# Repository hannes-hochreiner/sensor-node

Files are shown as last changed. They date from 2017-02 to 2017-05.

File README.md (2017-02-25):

# Sensor Node
A simple wireless sensor node.

## Requirements
  * measurements of temperature and humidity
  * wireless operation
  * cost of parts for one node <= 30 EUR
  * one measurement per minute, if a change larger than 10 % is observed; otherwise, one measurement every 10 minutes

  * MCU architecture needs to be ARM Cortex M0 (because I was interested in the platform as a replacement for AVR MCUs)
  * no leadless parts (because I was not equiped to solder them)

## Outline
The plan was to just quickly throw together a sensor, an MCU, a wireless module and a battery.

### MCU selection
I choose to go with the EFM32ZG222F32, because it was fairly cheap, low power and seemed to have good documentation.
As a bonus it has AES encryption functions, which makes the radio selection easier.
I also checked out Silicon Labs IDE and quite liked it.

Other candidates where the LPC81/2 (higher power and no AES) and the STM32F03 (no AES).

### Sensor selection
Adafruit Si7021 breakout board.
Seems to be a good sensor, which I could get my hands on for a reasonable price.
My preference would have been to use the sensor without the breakout board, but since it came in a leadless package I needed the breakout board.

### Wireless chip selection
The Si4012, because it is cheap and has very good documentation.

## Details

### Power and decoupling for the EFM32ZG
I found the recommended power and decoupling setup in Silicon Labs' "AN0002 Hardware Design Considerations".
The summary is, VSS go directly to ground, VDD_DREG gets 0.1 µF and 10 µF, DECOUPLE gets 1 µF, IOVDD get 0.1 µF each and one 10 µF, and AVDD get 10 nF each and one 10 µF.

### Power and decoupling for the Si4012
I followed the recommendation of the datasheet.
VDD got 1µF and the power supply for TXM and TXP got an LC filter with 220 nH and 0.5 pF resulting in a band pass of about 480 MHz.

### Power and decoupling for the Si7021
Ground was connected to a GPIO to be able to disable the module when it is not in use.
Decoupling has to be checked.

### External oscillators
I figured that I did not need any external oscillators since the communication on the board worked over I2C (which has a clock signal) and the radio claimed to have an internal oscillator that was precise enough.

### I2C
The three major things to consider with I2C seemed to me to be the addresses that are used, the speed the modules can handle and the pull-ups that are required.

Addresses and speeds are fairly easy to obtain.
A quick look into the datasheets told me the following:

  * Si7021: address: 0b1000000x; speeds: max 400 kHz; does clock strechting over 100 kHz.
  * Si4012: address: 0b1110000x (configurable); speeds: 100 kbps and 400 kbps.

When it comes to the pull-ups, it gets a little bit trickier.
However, I found a lot of documentation on the net explaining how to calculate the suitable intervals.
I used the Texas Instruments Application Report SLVA689 from February 2015.

I started out by calculating the maximum value, which depends essentially on the bus capacitance and the speed.
The bus capacitance is the capacitance of the pins plus that of the trace.
One problem I had was that I was not able to find any values for the capacitance the pins of my chosen chips added to the bus in the datasheets.
After investigating the topic for a while, I concluded that 10 pF should be a fairly conservative assumption.

To calculate the trace capacitance, I used the online calculator of the [Missouri University of Science and Technology](http://emclab.mst.edu/pcbtlc2/microstrip/).
The required parameters I obtained from OSHPark ([2 Layer Prototype](http://docs.oshpark.com/services/two-layer/), [2 Layer 2oz 0.8mm](http://docs.oshpark.com/services/two-layer-hhdc/)).
I assumed a trace width of 10 mils.

  * <0.5 pF / cm for the 2 layer prototype service
  * <0.6 pF / cm for the 2 layer 2 oz 0.8mm service

Given that there were three ICs on the bus and that the trace length would be smaller 3 cm, I estimated that the bus capacitance should be smaller 35 pF.
From that, I calculated the maximum resistance for the pull-ups at different speeds.

  * 33 kOhm for 100 kHz
  * 10 kOhm for 400 kHz

I tried calculating the minimum values for the pull-up resistors for all ICs.
However, only the datasheet of the Si7021 provided the required values.
The minimum resistance for the Si7021 was 1.1 kOhm.
I took this value as a representative value of all involved ICs.

In the end, I decided to go with 400 kHz transmission speed using 10 kOhm pull-ups.
One thing to note is that the Si4012 had a 50 kOhm integrated pull-up.
Hence the 10 kOhm would effectively only be about 8.5 kOhm.
I figured that this should give me an additional margin, but it was also something I had to consider at the time of calculating the battery life.

### Antenna
I chose to go with a loop antenna, because I have had problems with dipole antennas in the past.
Often the dipole antennas worked fine on the breadboard, but in the finished product the performed considerable worse.
Since I don't have the equipment to do an in-depth analysis, I left with (more or less educated) guesses.
I attributed the drop in antenna performance to the fact that the breadboard was acting as a ground plane.
In the finished sensor, there was no comparable ground plane and therefore the performance was worse.
As I was trying to get the sensors as compact as possible and I did not want to go higher frequencies, I thought that loop antennas were my best shot.
They are relatively small, don't need a ground plane and can be printed on the PCB.

To tune the antenna size, I wrote a small program.
I based my calculations of the loop inductance on a NIST paper ([E.B. Rosa "The self and mutual inductances of linear conductors," Bulletin of the Bureau of Standards, vol. 4, no. 2, p. 301](http://nvlpubs.nist.gov/nistpubs/bulletin/04/nbsbulletinv4n2p301_A2b.pdf)).
This paper gave a closed form equation for the conductance of a rectangular loop, while in the application notes I could only find conversions to equivalent circular structures.
The results were within 5 % of the approximations found in the application notes.

I calculated the size of the feed loop based on two different application notes.
[Microchip AN831](http://ww1.microchip.com/downloads/en/AppNotes/00831b.pdf) seemed to use a simpler approach basically neglecting the effect of the PCB.
[Silicon Labs AN639](http://www.silabs.com/Support%20Documents/TechnicalDocs/AN639.pdf) took the effect of the PCB into account, but used empirical factors to do so.
Although I thought it would be good to take the effect of the PCB into account, I wasn't quite sure the assumptions for the empirical factors help for my design.

With both approximations, I obtained about -8 dB for the estimated gain.
The length of the feed loop came out quite differently (10.5 mm to 16.1 mm).
In the end I decided to go with 14 mm, because I figured that it would be easier to compensate for a slightly to large loop than for a slightly to small loop.

### SWD
I added a 10 pin Cortex Debug connector based on the [ARM recommendation](http://infocenter.arm.com/help/topic/com.arm.doc.faqs/attached/13634/cortex_debug_connectors.pdf).

### BOM

A detailed bill of materials can be found on a [sub-page](bom.md).

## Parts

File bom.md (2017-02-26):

# BOM

amount|description|manufacturer|supplier|price per unit / EUR
------|-----------|------------|--------|--------------------
1|[EFM32ZG222F32 QFP48 microcontroller](https://hbe-shop.de/Art-2503912-SILICON-LABS-EFM32ZG222F32-QFP48T-MCU-32BIT-CORTEX-M0-24MHZ-TQFP-48)|Silicon Labs|hbe|2.24
1|[PCB 30mm x 54mm 2oz](http://docs.oshpark.com/services/two-layer-hhdc/)|OSH Park|oshpark|4
1|box|local|local|3.5
1|[CR2032 battery holder](https://www.voelkner.de/products/8982/Knopfzellen-Batteriehalter-Hu2032-Lf.html)|renata|voelkner|0.59
1|[battery CR2032](https://www.voelkner.de/products/770689/HyCell-Knopfzelle-CR-2032-Lithium-CR-2032-200-mAh-3-V-2-St..html)|various|voelkner|0.45
2|[resistor 10kOhm](https://hbe-shop.de/Art-2447553-MULTICOMP-MCWR08X1002FTL-DICKSCHICHTWIDERSTAND-10K-1-0125W-0805)|Multicomp|hbe|0.01
1|[Si4012 rf transmitter](https://hbe-shop.de/Art-2414359-SILICON-LABS-SI4012-C1001GT-RF-TRANSMITTER-27-960MHZ-MSOP-10)|Silicon Labs|hbe|1.15
1|[inductor 220nH](https://hbe-shop.de/Art-2470315-MURATA-LQW2BASR22J00L-INDUKTIVITAET-220NH-04A-5-820MHZ)|Murata|hbe|0.22
1|[capacitor 0.5pF](https://hbe-shop.de/Art-1759178-MULTICOMP-MC0805N0R5C500CT-KONDENSATOR-MLCC-C0G-NP0-05PF-50V-0805)|Multicomp|hbe|0.04
2|[capacitor 1pF](https://hbe-shop.de/Art-7568398-AVX-08052U1R0BAT2A-HF-KONDENSATOR-C0G-NP0-1PF-200V-0805)|AVX|hbe|0.7
2|[capacitor 1µF](https://hbe-shop.de/Art-1759422-MULTICOMP-MC0805F105Z160CT-KONDENSATOR-MLCC-Y5V-1UF-16V-0805)|Multicomp|hbe|0.04
4|[capacitor 0.1µF](https://hbe-shop.de/Art-1759167-MULTICOMP-MC0805F104Z250CT-KONDENSATOR-MLCC-Y5V-100NF-0805)|Multicomp|hbe|0.02
4|[capacitor 10µF](https://hbe-shop.de/Art-2320852-MULTICOMP-MC0805X106K6R3CT-KONDENSATOR-MLCC-X5R-10UF-63V-0805)|Multicomp|hbe|0.08
2|[capacitor 10nF](https://hbe-shop.de/Art-1759246-MULTICOMP-MC0805B103K500CT-KONDENSATOR-MLCC-X7R-10NF-50V-0805)|Multicomp|hbe|0.02
1|[Si7021 humidity sensor breakout board](http://www.exp-tech.de/adafruit-si7021-temperature-humidity-sensor-breakout-board)|Adafruit|exp-tech|7.5
1|[header 1x5 straight](https://www.voelkner.de/products/130623/Praezisions-Stiftleiste-1x20-Verg-Rm-2-5.html)|BKLElectronic|voelkner|0.37
1|[socket 0.25 x 1x20 straight](https://www.voelkner.de/products/882107/Connfly-Buchsenleiste-Praezision-Anzahl-Reihen-1-Polzahl-je-Reihe-20-93040C2-1-St..html)|Connfly|voelkner|0.13
1|[Cortex Debug shrouded header](https://www.voelkner.de/products/877289/W-P-Products-Stiftleiste-Rastermass-1.27-mm-Polzahl-Gesamt-10-1-St..html)|W+P|voelkner|0.61
|**total**|||**22.74**

## Cost for 3 sensors
supplier|price of goods|shipping|total
--------|--------------|--------|-----
HBE|21.37|8.45|29.82
OSH Park|12|0|12
local shop|10.5|0|10.5
Voelkner|7.4|4.95|12.35
EXP-TECH|22.5|3.5|26
**total**|||90.67

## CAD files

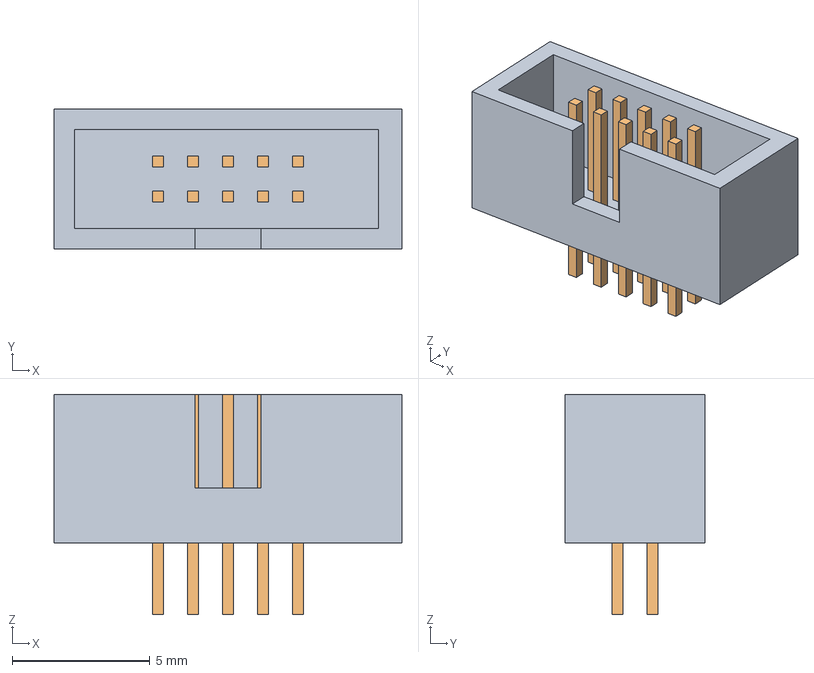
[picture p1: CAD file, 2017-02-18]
freecad/shroudedHeader.fcstd
12.7 x 5.10 x 8.00 mm
shroud
pins

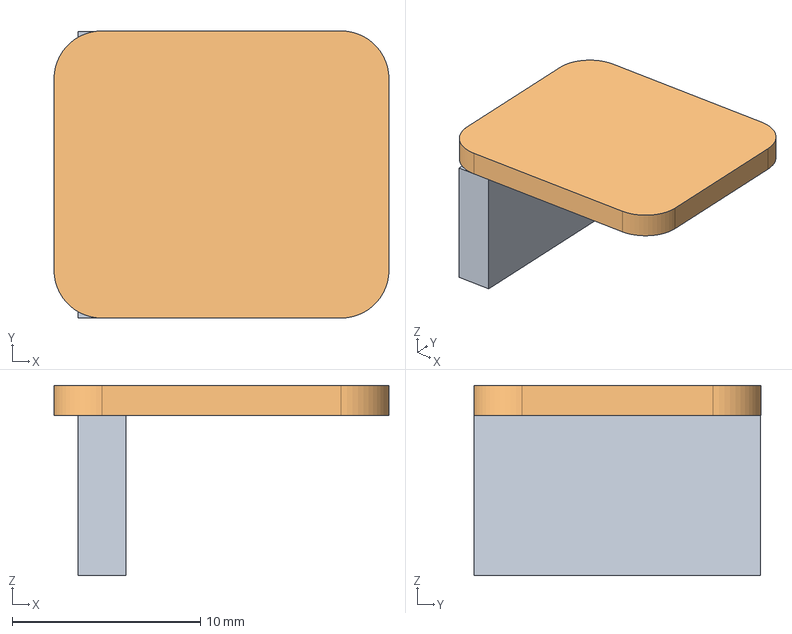
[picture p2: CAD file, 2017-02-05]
freecad/si7021_breakout.fcstd
17.8 x 15.2 x 10.1 mm
female header

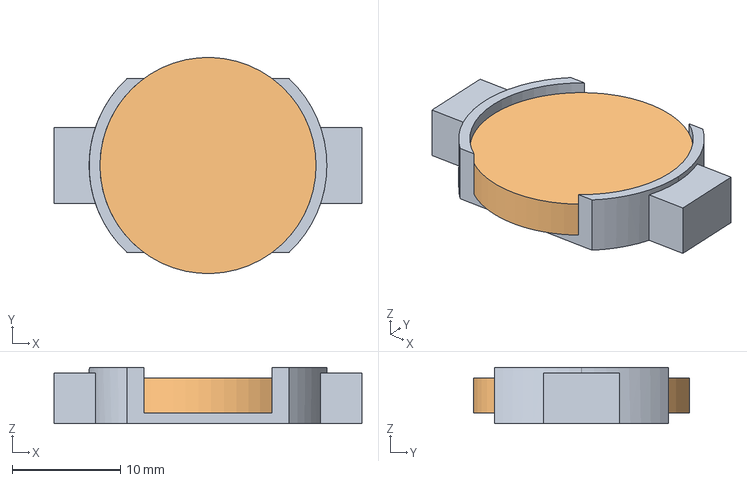
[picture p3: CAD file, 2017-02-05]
freecad/batteryHolder.fcstd
28.5 x 20.0 x 5.20 mm
battery holder
battery

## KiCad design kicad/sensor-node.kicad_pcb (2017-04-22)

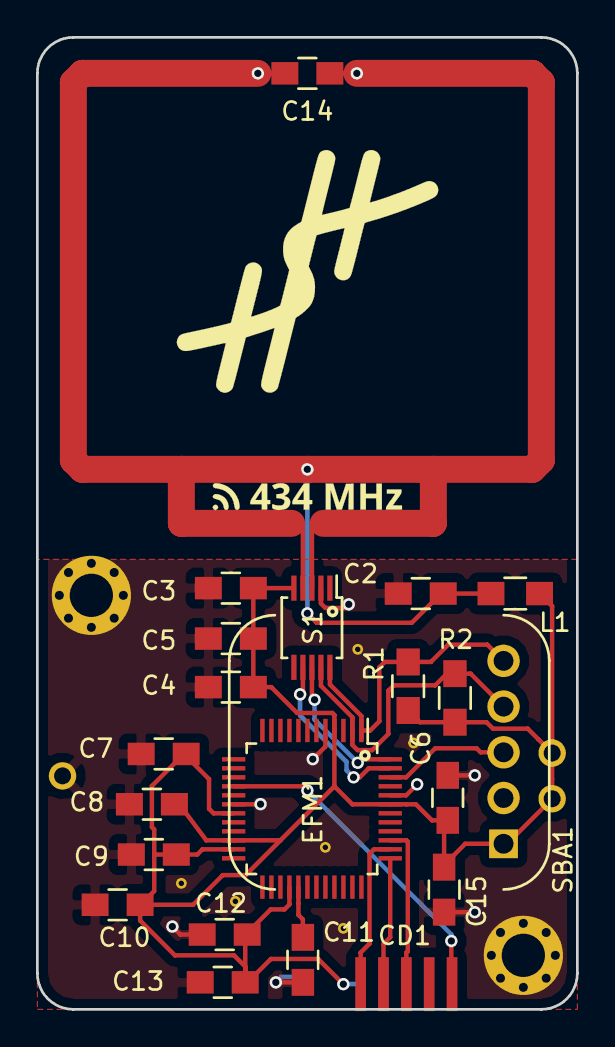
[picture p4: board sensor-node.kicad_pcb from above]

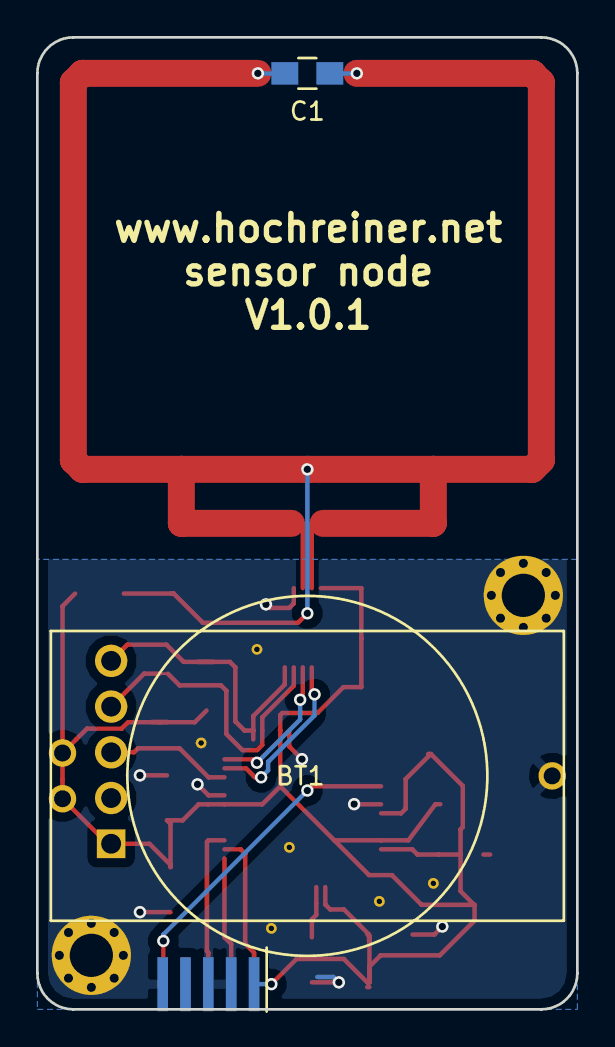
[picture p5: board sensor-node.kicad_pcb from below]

Board: 2 copper layers, 30.0 x 54.0 mm, 23 parts (2 on the bottom side), 13 nets.

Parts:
BT1: CR2032Holder; HU2032-LF
C1, C14: 1pF; C_0805_HandSoldering
C2: 0.5pF; C_0805_HandSoldering
C3, C11: 1µF; C_0805_HandSoldering
C4, C6, C8, C12: 0.1µF; C_0805_HandSoldering
C5, C10, C13, C15: 10µF; C_0805_HandSoldering
C7, C9: 10nF; C_0805_HandSoldering
CD1: CortexDebug; CORTEX-DEBUG-EDGE
EFM1: EFM32ZG222; TQFP-48_7x7mm_Pitch0.5mm
L1: 220nH; R_0805_HandSoldering
R1, R2: 10k; R_0805_HandSoldering
S1: Si4012; MSOP-10_3x3mm_Pitch0.5mm
SBA1: Si7021-BA; Si7021BA

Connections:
+3V3: BT1.1, C3.1, C4.1, C5.1, C6.2, C7.1, C8.1, C9.1, C10.1, C12.1, C13.1, C15.2, CD1.1, EFM1.4, EFM1.19, EFM1.22, EFM1.23, EFM1.28, EFM1.43, L1.1, R1.2, R2.2, S1.5, SBA1.1
/RAD_ENABLE: EFM1.48, S1.8
/RAD_INT: EFM1.47, S1.7
/SCL: EFM1.2, R2.1, S1.9, SBA1.4
/SDA: EFM1.1, R1.1, S1.10, SBA1.5
/SWCLK: CD1.4, EFM1.37
/SWDIO: CD1.2, EFM1.38
/SWO: CD1.6, EFM1.39
/~RESET: CD1.10, EFM1.16
/~SEN_ENABLE: EFM1.46, SBA1.3
GND: BT1.2, C2.2, C3.2, C4.2, C5.2, C6.1, C7.2, C8.2, C9.2, C10.2, C11.1, C12.2, C13.2, C15.1, CD1.3, CD1.5, CD1.9, EFM1.5, EFM1.18, EFM1.44, S1.2
unnamed: C1.1, C1.2, C2.1, C14.1, C14.2, L1.2, S1.3, S1.4
unnamed: C11.2, EFM1.29

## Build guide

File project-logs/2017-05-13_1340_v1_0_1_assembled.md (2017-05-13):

# Version 1.0.1 assembled

Today, I mostly assembled one of the version 1.0.1 boards.
For the time being, I left out the sensor socket and the battery.
The sensor I already tested and I can't attach the battery holder as long as sensor socket is not attached.

The electrical and first MCU communication tests looked ok.
Next up are the radio chip tests.
Followed, of course, by the actual radio transmission test.

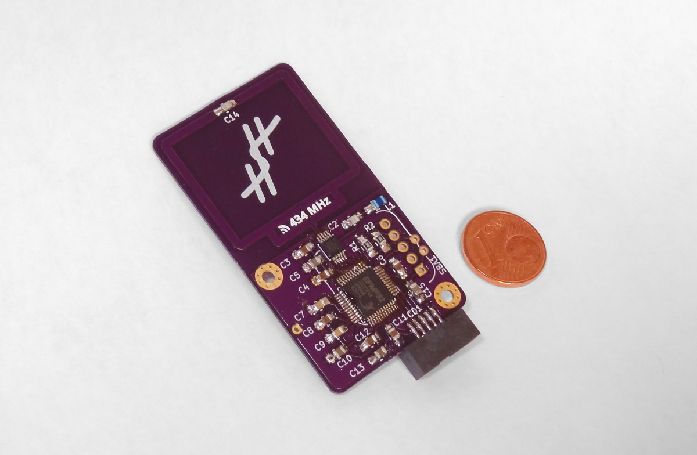
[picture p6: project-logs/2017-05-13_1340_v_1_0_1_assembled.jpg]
pcb version 1.0.1 assembled


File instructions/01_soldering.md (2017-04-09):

# Soldering
The order for soldering the components that worked best for me so far was:

  * MCU
  * capacitors
  * radio IC
  * rest

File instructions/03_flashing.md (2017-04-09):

# Flashing the MCU
I decided to use the Adafruit FT232H breakout board in combination with OpenOCD for flashing the MCU.

## Installing OpenOCD
Since I was using Fedora at the time, installing OpenOCD was as easy as typing:

```
sudo dnf install -y openocd
```

## FT232H module configuration
I started out using the "resistor hack" (interface/ftdi/swd-resistor-hack.cfg) configuration.
It worked ok, but had the drawback that it needed additional parts.

There is an ["official" configuration](http://openocd.zylin.com/#/c/2274) being worked on.
Hence, I am hopeful that the support for the FT232H module will get better soon.
For the time being, I pieced together a configuration with what I found around the web.
It is mainly based on [adafruit-ft232h-swd.cfg](http://openocd.zylin.com/#/c/4075/1/tcl/interface/ftdi/adafruit-ft232h-swd.cfg) by Roger Lendenmann.

## Connecting the adapter
The adapter connection is described in [adafruit-ft232h-swd.cfg](http://openocd.zylin.com/#/c/4075/1/tcl/interface/ftdi/adafruit-ft232h-swd.cfg).

## Flashing the chip
To flash the chip, I started OpenOCD in one terminal.
```
cd openocd
openocd -f sensor-node.cfg
```

Then, I opened a second terminal to connect to it via telnet.
```
$ telnet localhost 4444
Trying 127.0.0.1...
Connected to 127.0.0.1.
Escape character is '^]'.
Open On-Chip Debugger
> program ../sensor-node.hex verify reset
target halted due to debug-request, current mode: Thread
xPSR: 0x81000000 pc: 0x00000164 msp: 0x20001000
** Programming Started **
auto erase enabled
detected part: EFM32 Zero Gecko - Rev: 139
flash size = 32kbytes
flash page size = 1024bytes
wrote 3072 bytes from file ../sensor-node.hex in 0.180560s (16.615 KiB/s)
** Programming Finished **
** Verify Started **
verified 2888 bytes in 0.036852s (76.531 KiB/s)
** Verified OK **
```

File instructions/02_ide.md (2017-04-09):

# IDE
I used "Simplicity Studio" as the IDE.
To install it, I followed the instructions on the Silicon Labs website.

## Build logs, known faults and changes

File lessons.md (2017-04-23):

# Lessons learned

  * The card edge contacts for the SWD connector (0.05" pitch) work perfectly with the OSH Park 2oz boards
  * An additional pin 1 indicator is required for the MSOP10 and QFP48 footprints in KiCAD as the ones included in the default footprints are not visible on the PCBs
  * The decoupling capacitors are really important
  * It is really nice to be able to debug programs on the chip

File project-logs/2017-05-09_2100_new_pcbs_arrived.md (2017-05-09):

# New PCBs arrived!

Big shout-out and thank you to [OSH Park](https://oshpark.com/) who did everything in his power to deliver the new version of my board as fast as possible!
While I expected that the new PCBs would take 5-6 weeks to arrive, it took little more than 2 weeks.
Really exceptional service.

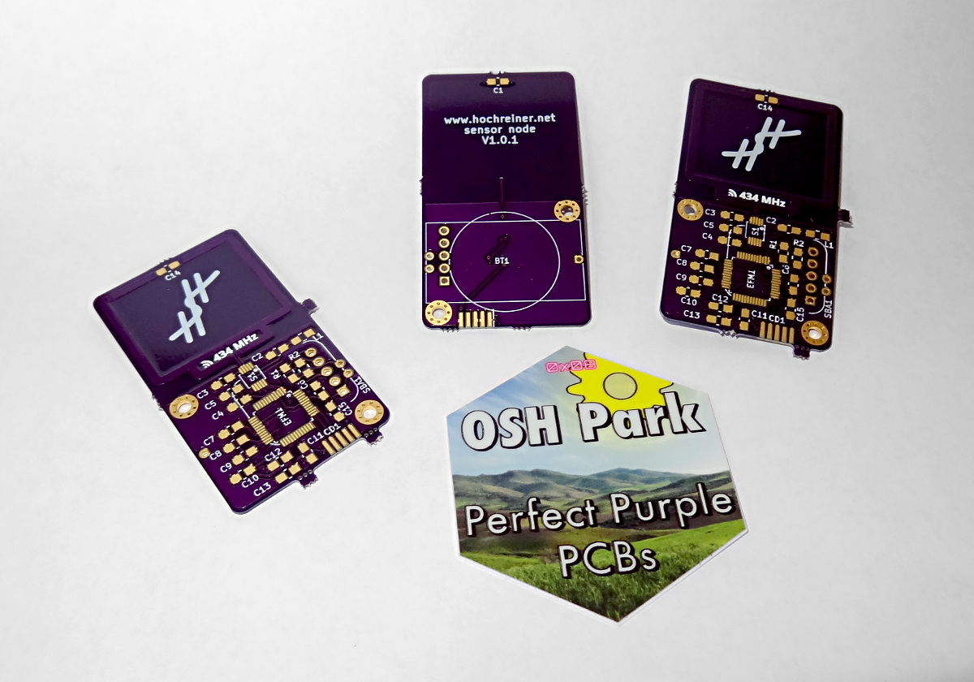
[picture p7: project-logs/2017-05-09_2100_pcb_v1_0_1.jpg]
pcb version 1.0.1 on arrival


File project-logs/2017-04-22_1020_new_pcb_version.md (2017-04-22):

# New version of the board ordered

Today, I ordered version 1.0.1 of the board from [OSH Park](https://oshpark.com/).
With this version, I fixed the pin assignment of the radio chip, added pin 1 indicators for the MCU and the radio chip, and added more ground plane copper on the top layer.
It will probably take more than a month until I get the boards delivered, but I am really looking forward to playing with them.

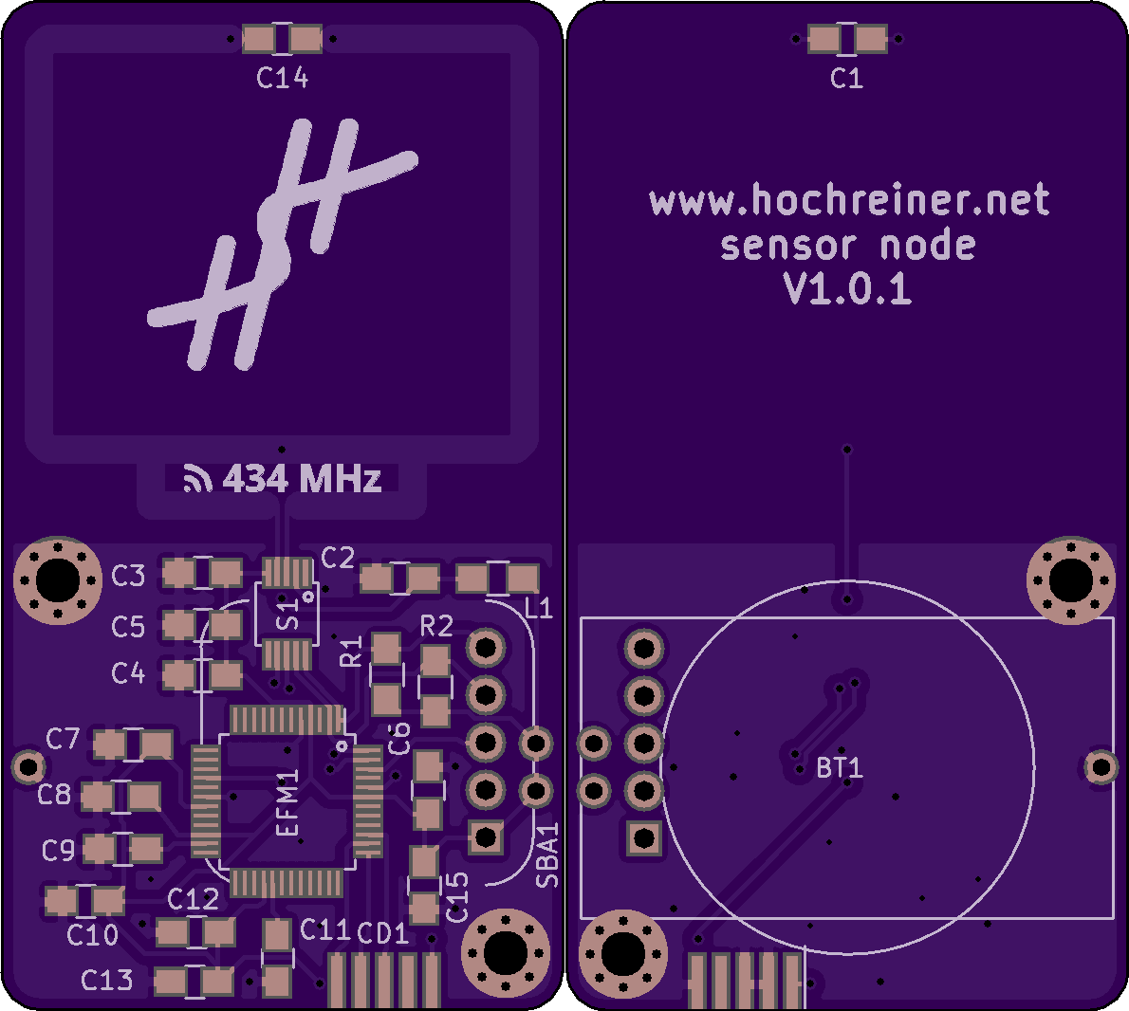
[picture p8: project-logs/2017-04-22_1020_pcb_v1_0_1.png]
pcb version 1.0.1


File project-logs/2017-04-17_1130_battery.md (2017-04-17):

# Battery operation test completed

I finally ran the last test I wanted to do with the current version of the board: the battery operation test.
Since it was unclear to me from the documentation of the sensor breakout board whether it would operate normally below 3.3 V, I gave it a try.
I powered the board from the CR2032, which my multi-meter claimed to be 3.05V, and looked at the measurement results in the debugger.
Everything, seemed to work fine.
The next step will be to order a new batch of boards with the correct pin assignment for the radio chip.
I am really looking forward to seeing the full assembly work.

Background on the breakout board power confusion:
On the [Adafruit description page](https://learn.adafruit.com/adafruit-si7021-temperature-plus-humidity-sensor) of the breakout board it claims to work from 3-5 volts input and both 3.3V and 5V logic.
However, I also had a look at the circuit diagram and the model of regulator chip ([Microchip MIC5225-3.3](http://www.microchip.com/wwwproducts/en/MIC5225)) that has been used.
This chip is rated to output 3.3V with a dropout voltage of typically about 300mV at full load.
My confusion was mainly that I thought that below about 3.3V (actually rather 3.6V) it would not work.
This did not fit with the documentation and also did not reflect what I experienced powering the breakout board from a 3.3V source.
Now that I tried with a 3V source and had another read of the data sheet, I think the more accurate interpretation is that below 3.6V the regulator chip rated for 3.3V cannot provide the 3.3V anymore.
Even so, it does not go to zero straight away.
There is actually a nice graph in the data sheet showing the output voltage remains about 0.5V below the input voltage down to about 2.3V.
Only then it drops to zero.
Since the sensor chip works down to 1.9V, everything should work out just fine down to a battery voltage of about 2.4V.

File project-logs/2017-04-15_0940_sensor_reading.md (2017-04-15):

# Reading sensor values
Reading the sensor values turned out to be pretty straight forward.
The emlib provides a nice abstraction for handling I2C communication.
Furthermore, there are a few examples that can be found around the web.
In the first iteration, I took the simplest approach by using blocking mode (clock stretching) requests.
I think that I could gain some efficiency in setting up DMA driven I2C communication, but I figured it might be better to start simple.

The actual code can be found on [GitHub](https://github.com/hannes-hochreiner/sensor-node/blob/08b46bc856f15618d4c0e9fb8b632ffcaa449f23/firmware/src/main.c).
I used GDB to load and debug the code on the MCU.
Having only worked with 8-bit AVR, I really enjoyed being able to debug the code directly on the MCU.
Although I cannot debug the code right in the IDE, it is still so much better to have GDB session with full access to memory and breakpoints than trying to debug code using printf and blinking LEDs.

For completion, here is a condensed version of the GDB session:
I started OpenOCD in one terminal:
```
$ openocd -f sensor-node.cfg
```
Then, I opened a second terminal to start GDB:
```
$ arm-none-eabi-gdb sensor-node.axf
(gdb) target remote :3333
(gdb) monitor reset halt
(gdb) load `sensor-node.axf' has changed; re-reading symbols.
Loading section .text, size 0x166c lma 0x0
Loading section .ARM.exidx, size 0x8 lma 0x166c
Loading section .data, size 0x74 lma 0x1674
Start address 0x164, load size 5864
Transfer rate: 12 KB/sec, 1954 bytes/write.
(gdb) b main.c:50
(gdb) c
Continuing.

Breakpoint 1, main () at ../src/main.c:50
50          for(volatile long i=0; i<100000; i++)
(gdb) p ret
$1 = i2cTransferDone
(gdb) p/x rx_buffer
$2 = {0x7b, 0x7e}
```
Which yielded the plausible value of about 54% relative humidity.

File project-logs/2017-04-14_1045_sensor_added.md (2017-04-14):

# Sensor added

I just added the I2C pull-ups and the sensor socket to the board.
For the time being, this is the final state of this version of the board.
There is no point in adding the radio components, as the pin assignment has to be corrected.
However, I can attach the sensor and test the communication between the sensor and the MCU now.

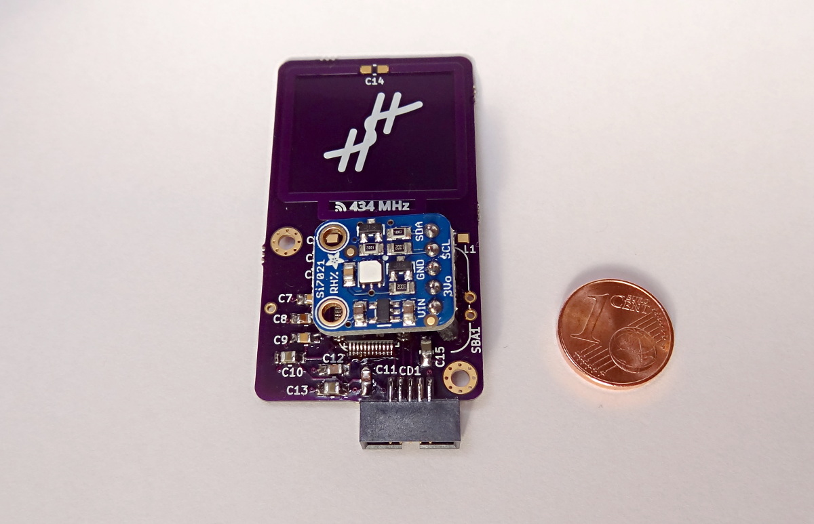
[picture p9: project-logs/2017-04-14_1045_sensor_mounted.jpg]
test board with the sensor attached


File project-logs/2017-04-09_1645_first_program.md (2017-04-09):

# First program
Today, I learned an interesting lesson: decoupling capacitors matter.

For the last few days, I had been stuck with a problem: reading from the MCU worked, but flashing a new program always failed.
I started going through all possible causes (OpenOCD configuration, physical connections, ...), but I could not find the cause of the problems.
Then I remembered reading recently that the decoupling capacitors are not only there to cope with ripples in the power supply, but also to smooth out the varying power demand of the MCU.
Therefore, I decided to add the decoupling capacitors and give the board another try:

```
> program sensor-node.hex verify
target halted due to debug-request, current mode: Thread
xPSR: 0x01000000 pc: 0x00000164 msp: 0x20001000
** Programming Started **
auto erase enabled
wrote 3072 bytes from file sensor-node.hex in 0.173291s (17.312 KiB/s)
** Programming Finished **
** Verify Started **
verified 2888 bytes in 0.036685s (76.879 KiB/s)
** Verified OK **
```

Fortunately this time everything worked without errors.

Coming from a background of working with Atmel 8-bit chips, which work quite well without decoupling, the solution to this problem was not all that obvious to me.
However, I think it was a valuable lesson in building robust designs.

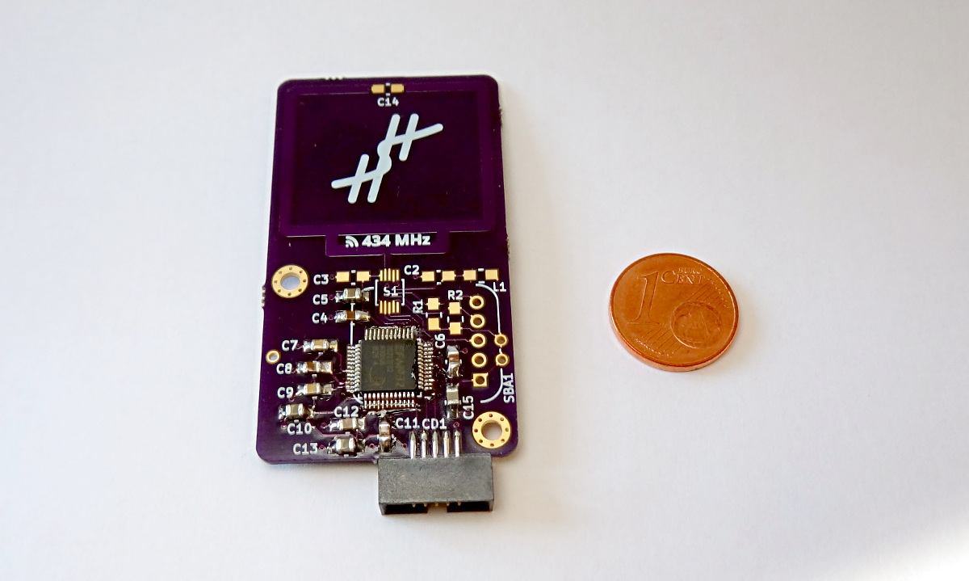
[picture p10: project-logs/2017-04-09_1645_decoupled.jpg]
sensor node board with decoupling capacitors added


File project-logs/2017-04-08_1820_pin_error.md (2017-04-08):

# Wrong pin assignment

As I was getting ready to solder the radio chip (Si4012), I realized that the pin assignment for this chip was wrong.
This is - obviously - not ideal.
While the problem is easily fixable and the financial hit of ordering new boards is bearable (< 15 EUR), the additional delay (3-5 weeks) is quite severe.
However, there are still a few things I can do with the boards as they are now:

  * check that programming the MCU works
  * check the communication with the sensor
  * check that the sensor works with the voltage the battery is able to supply

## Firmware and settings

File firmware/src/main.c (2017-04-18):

#include "em_device.h"
#include "em_chip.h"

#include "InitDevice.h"
#include "sensor.h"

int main(void)
{
  /* Chip errata */
  CHIP_Init();

  // Add some delay
  for(volatile long i=0; i<200000; i++)
    ;

  enter_DefaultMode_from_RESET();

  /* Infinite loop */
  while (1) {
    uint16_t hum, tmp;

    readSensor(&hum, &tmp);

    // Add some more delay
    for(volatile long i=0; i<100000; i++)
      ;
  }
}

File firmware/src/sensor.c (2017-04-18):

/*
 * sensor.c
 *
 *  Created on: Apr 18, 2017
 *      Author: Hannes Hochreiner <hannes@hochreiner.net>
 */

#include "sensor.h"

int readSensor(uint16_t* humidity, uint16_t* temperature) {
  I2C_Init_TypeDef i2c_init = {
    .enable = true,                              // enable I2C
    .master = true,                              // I2C master
    .refFreq = 0,                                // measure reference clock
    .freq = I2C_FREQ_FAST_MAX,                   // 400kbps fast mode
    .clhr = i2cClockHLRAsymetric,                // use 6:3 bit ratio
  };
  I2C_Init(I2C0, &i2c_init);

  uint8_t sensor_addr = 0x40;
  uint8_t comReadHumidity = 0xE5;
  uint8_t comReadTemperature = 0xE0;
  uint8_t buf[2];

  I2C_TransferReturn_TypeDef ret; // I2C state tracker

  I2C_TransferSeq_TypeDef msg = {
    .addr = (sensor_addr << 1),            // set sensor slave address
    .flags = I2C_FLAG_WRITE_READ,          // indicate basic write
    .buf[0].data = &comReadHumidity,       // point to tx_buffer
    .buf[0].len = 1,                       // specify number of bytes
    .buf[1].data = buf,
    .buf[1].len = 2
  };

  ret = I2C_TransferInit(I2C0, &msg);      // start I2C write transaction with sensor
  while(ret == i2cTransferInProgress) {    // continue until all data has been sent
    ret = I2C_Transfer(I2C0);
  }

  *humidity = buf[0] << 8 | buf[1];

  msg.buf[0].data = &comReadTemperature;

  ret = I2C_TransferInit(I2C0, &msg);      // start I2C write transaction with sensor
  while(ret == i2cTransferInProgress) {    // continue until all data has been sent
    ret = I2C_Transfer(I2C0);
  }

  *temperature = buf[0] << 8 | buf[1];

  return 0;
}

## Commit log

2017-01-10 updated the sensor selection
2017-01-12 started circuit diagram
    [sensor-node.kicad_pcb, sensor-node.sch]
2017-01-14 added basic wiring for the MCU and the radio
    [sensor-node.sch]
2017-01-14 added sensor
    [sensor-node.sch]
2017-01-14 added I2C design
2017-01-19 updated pull-up values in the diagram
    [sensor-node.sch]
2017-01-21 added debug connector
    [sensor-node.sch]
2017-01-21 fixed some minor problems
    [sensor-node.sch]
2017-01-21 added some annotation
    [sensor-node.sch]
2017-01-21 started working on an antenna design tool
2017-01-22 added capacitance calculation
2017-01-22 added the velocity factor for the calculation of the radiation resistance
2017-01-22 updated the calculation of the trace resistance
2017-01-22 switched formatting
2017-01-22 switched tests to use d3-format
2017-01-24 started board layout
    [sensor-node.kicad_pcb, sensor-node.sch]
2017-01-24 started routing
    [sensor-node.kicad_pcb]
2017-01-24 extended bom
2017-01-25 added custom footprints
    [sensor-node.kicad_pcb, sensor-node.sch]
2017-01-26 continued routing
    [sensor-node.kicad_pcb]
2017-01-28 automated bom creation and moved it to a separate page
    [sensor-node.sch]
2017-01-28 added link to bom
2017-01-28 removed led
    [sensor-node.kicad_pcb, sensor-node.sch]
2017-01-28 removed uart
2017-01-28 updated bom
2017-01-29 added components that are not in the circuit diagram
2017-01-29 added missing components
    [sensor-node.kicad_pcb]
2017-01-31 minor routing changes
    [sensor-node.kicad_pcb]
2017-02-01 improved routing
    [sensor-node.kicad_pcb]
2017-02-02 more routing
    [sensor-node.kicad_pcb]
2017-02-03 added mounting holes and custom footprint for sensor module
    [sensor-node.kicad_pcb, sensor-node.sch]
2017-02-04 added board outline
    [sensor-node.kicad_pcb]
2017-02-04 more rounting and antenna planning
    [sensor-node.kicad_pcb]
2017-02-04 recalculated antenna
2017-02-04 redrew antenna
    [sensor-node.kicad_pcb, sensor-node.sch]
2017-02-05 adde model for the battery holder
    [batteryHolder.fcstd, sensor-node.kicad_pcb]
2017-02-05 added simple 3d model for the break out board
    [sensor-node.kicad_pcb, si7021_breakout.fcstd]
2017-02-06 switched supplier
2017-02-07 moved cortex debug connector futher to the right
    [sensor-node.kicad_pcb]
2017-02-07 moved mounting hole and battery slightliy down
    [sensor-node.kicad_pcb]
2017-02-07 moved inductivity up
    [sensor-node.kicad_pcb]
2017-02-09 check i2c connections
    [sensor-node.kicad_pcb]
2017-02-09 rounded antenna edges
    [sensor-node.kicad_pcb]
2017-02-11 refined feed loop size
    [sensor-node.kicad_pcb]
2017-02-11 added a decoupling capacitor
    [sensor-node.kicad_pcb, sensor-node.sch]
2017-02-11 improved silk screen decoration
    [sensor-node.kicad_pcb]
2017-02-11 updated design rules to OSH Park settings
    [sensor-node.kicad_pcb]
2017-02-18 added 3D model of the shrouded header
    [sensor-node.kicad_pcb, shroudedHeader.fcstd]
2017-02-25 added more description of the antenna choice
2017-03-12 added openocd configuration
    [sensor-node.cfg]
2017-04-09 added openocd config
    [sensor-node.cfg]
2017-04-09 added more documentation on flashing the chip
    [adafruit-ft232h-module-swd.cfg, sensor-node.cfg]
2017-04-15 modified firmware to include sensor
2017-04-17 fixed battery model name
2017-04-17 updated the kicad project
    [sensor-node.sch]
2017-04-17 fixed Si7012 pin assignment
    [sensor-node.kicad_pcb]
2017-04-17 minor fix of the board
    [sensor-node.kicad_pcb]
2017-04-17 increased version number of the board
    [sensor-node.kicad_pcb]
2017-04-17 added logo, mounting, and stitching vias
    [sensor-node.kicad_pcb]
2017-04-18 returned mounting hole to former position
    [sensor-node.kicad_pcb]
2017-04-18 added additional pin 1 indicators for ICs
    [sensor-node.kicad_pcb]
2017-04-22 updated pcb
    [sensor-node.kicad_pcb]
2017-04-22 added project log for new pcb version
